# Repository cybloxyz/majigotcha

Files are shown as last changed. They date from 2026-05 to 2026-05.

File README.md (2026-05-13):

# MAJIGOTCHA!
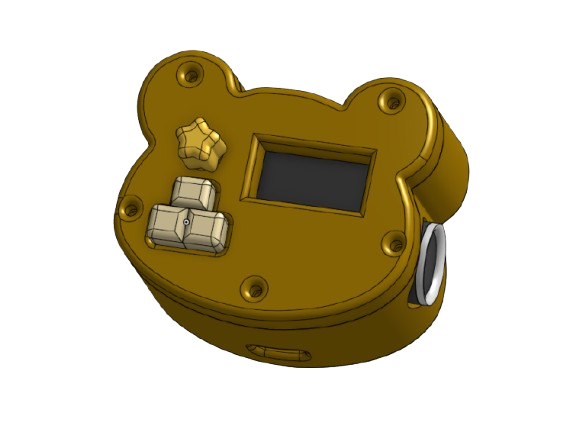
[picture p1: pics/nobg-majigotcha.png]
majigotcha

MAJIGOTCHA is a handheld digital pet in a small, bear head-shaped device. Users nurture a virtual creature from hatching through different life stages by feeding, cleaning, and playing with it using three buttons. Proper care determines its growth, while neglect can cause it to die.
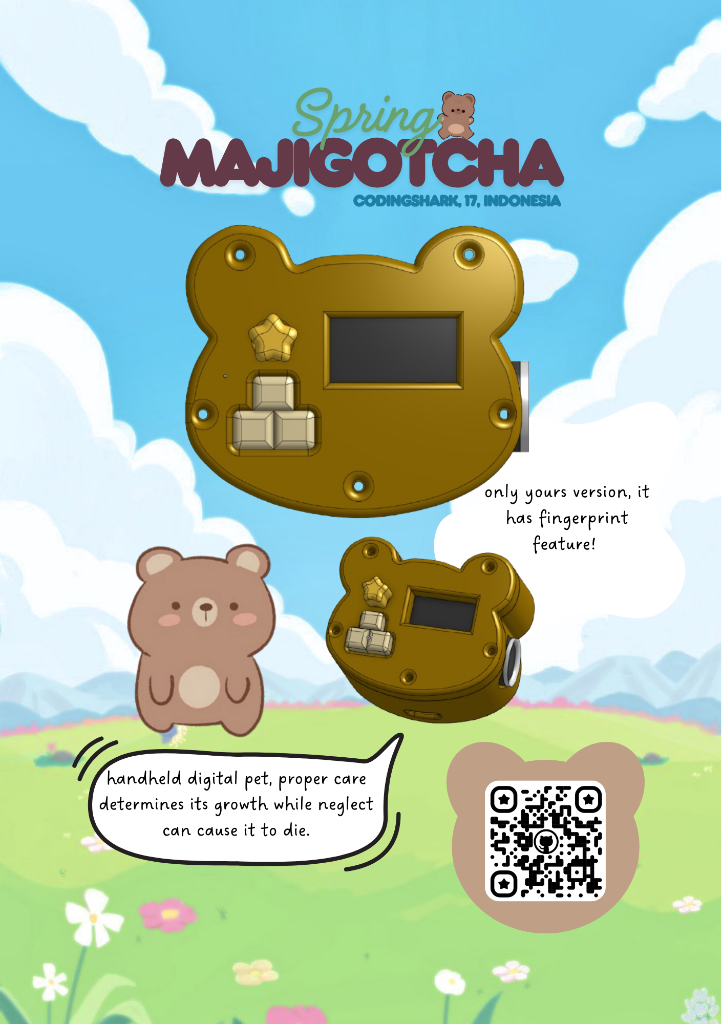
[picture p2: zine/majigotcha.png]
majigotcha zine


## why MAJIGOTCHA?
can't afford the real tamagotchi? yeah that is why i build my own, it is not tamagotchi it is MAJIGOTCHA, it has my dream features such fingerprint and touch sensor, i make this because my sister is really dream to have a tamagotchi but since it is too expensive to buy i prefer make this by my self, since i want something more than just a tamagotchi.

## features
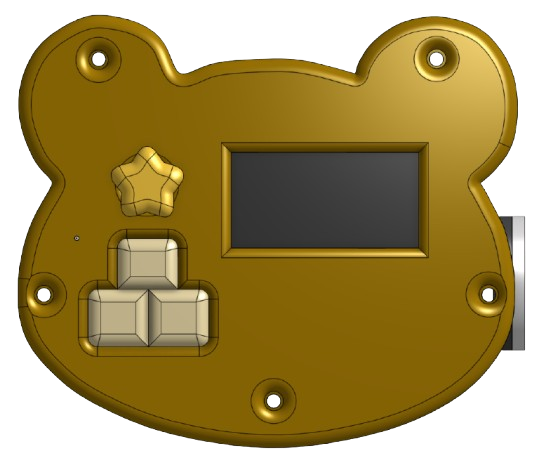
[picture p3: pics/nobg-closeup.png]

this is the first version of MAJIGOTCHA! it has really great features lemme break down:
> touch sensor, this mean you could pat your pet! tame it!

> fingerprint sensor, make it only yours..it will recognizes your fingerprint and can only be tamed with you.

> potentiometer scroll, since this MAJIGOTCHA has more complex features, the screen-menu could be navigate by potentiometer and button.

> in future i will upgrade this MAJIGOTCHA firmware to OTA and various casing.

## code example, pcb and schema
i made the case using [onshape](https://onshape.com) and here is the document link [MAJIGOTCHA-case](https://cad.onshape.com/documents/353c81332f9ae163598e6183/w/df33fd15e80ae307a4e30d2f/e/6c68072ba9f649a3b4a35ab0)
i am using RV09 vertical potentiometer so it will be solderen onPCB and for things such OLED, TTP223, HLK-ZW101 i use pinHeader 2.54 instead
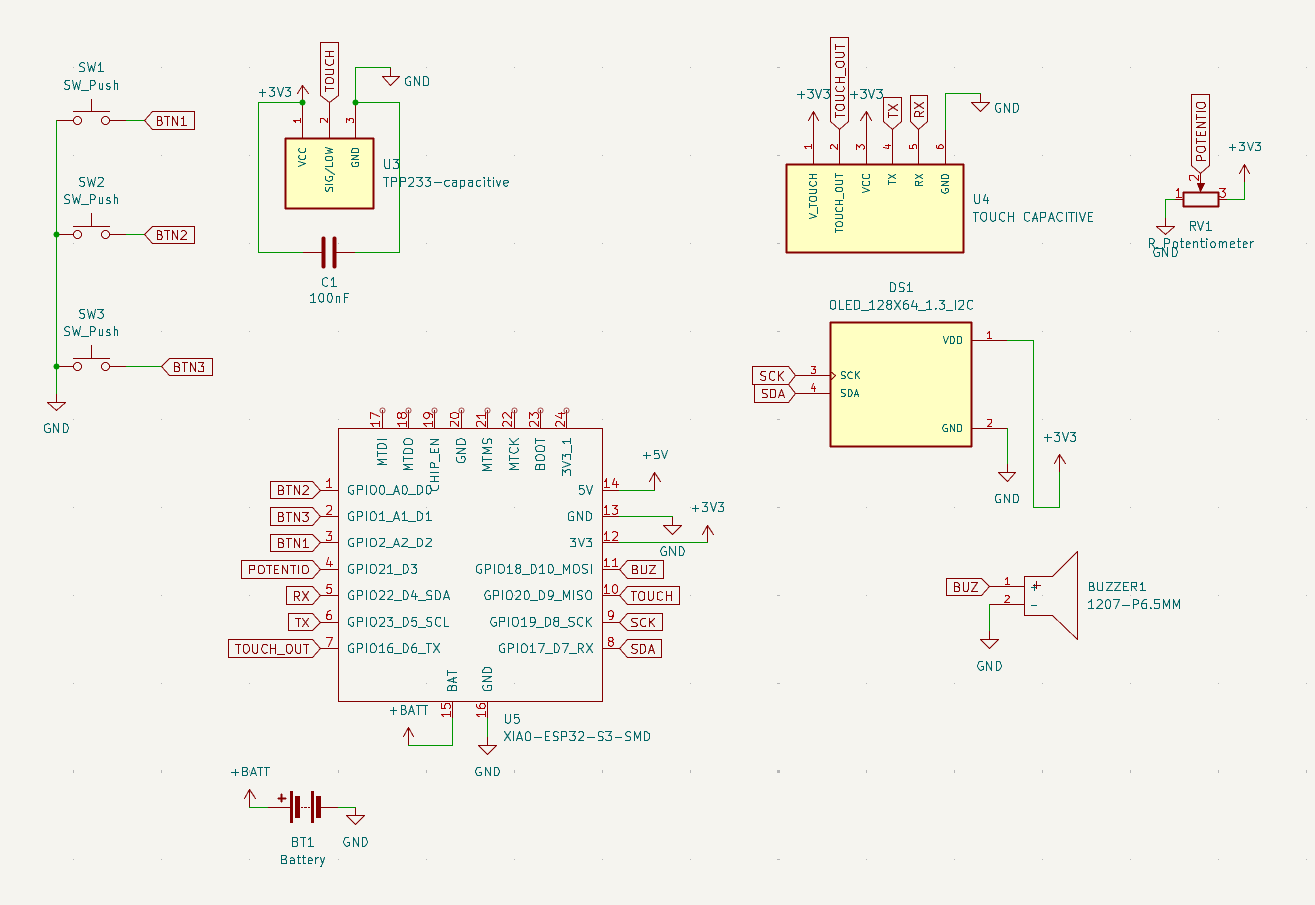
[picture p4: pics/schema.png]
schema

in this schema i'm using global labels since it is easier to understand and to read, for the PCB it is 2 layer, and contain vias, the pcb's size is not more than 50mmx50mm which it resulting in cheaper price.
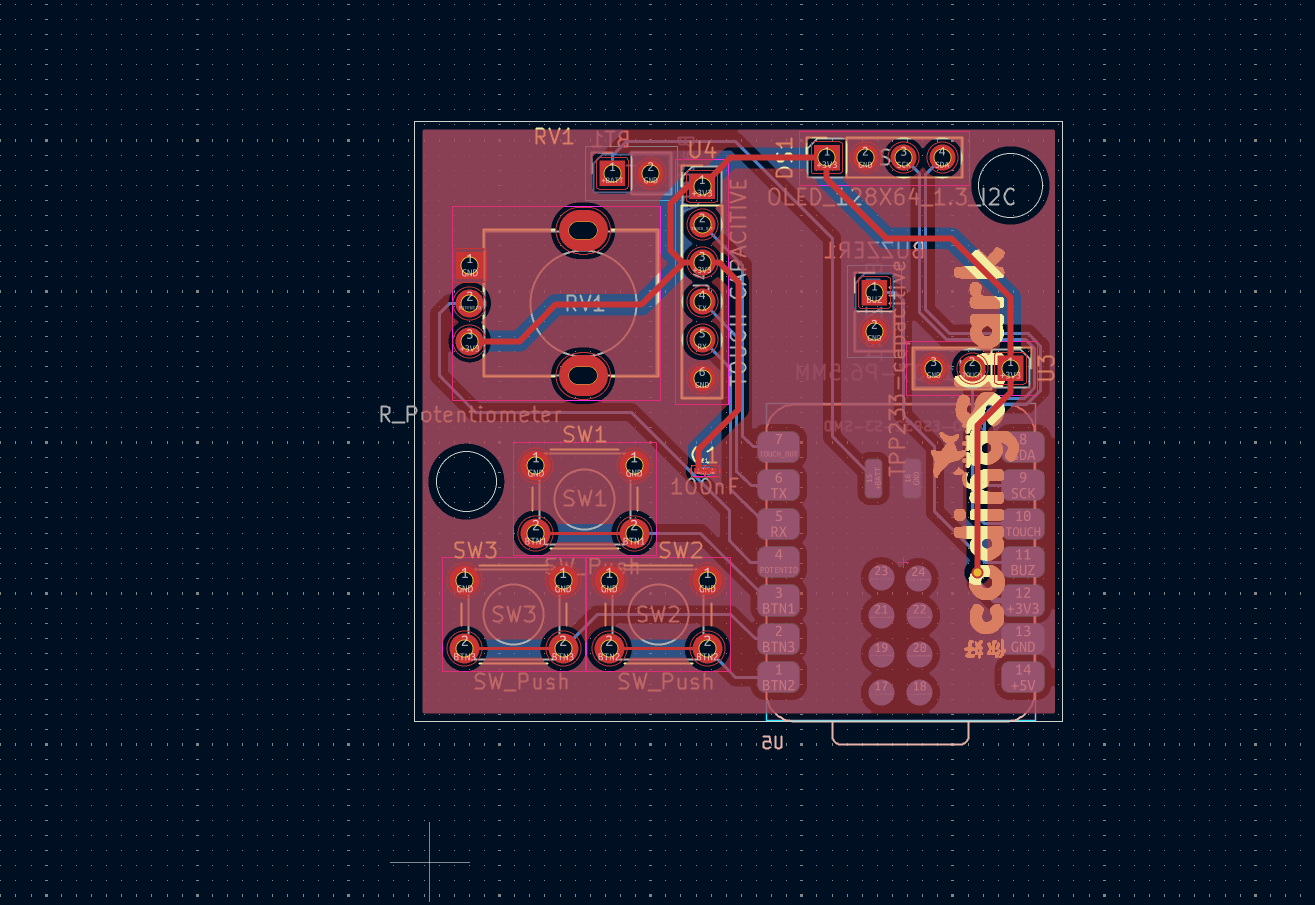
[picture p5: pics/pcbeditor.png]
pcb editor

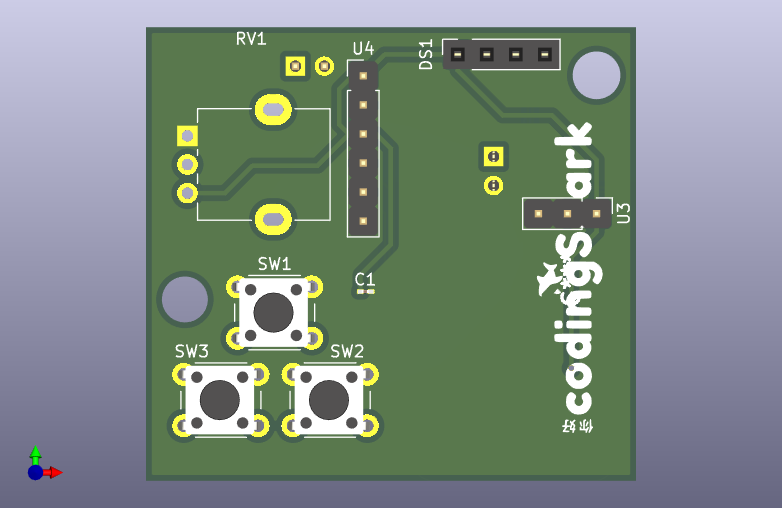
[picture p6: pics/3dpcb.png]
pcb


this MAJIGOTCHA is similar to tamagotchi BUT it is has more unique features, in here every stats even tame, inTamingProgress or notTame is has it own sprite, here is the bitmaps example:
```
const unsigned char PROGMEM notTame[] = {
  0b00000000, 0b00000000,
  0b00000000, 0b00000000,
  0b00001100, 0b01100000,
  0b00010011, 0b10010000,
  0b00010000, 0b00010000,
  0b00100100, 0b01001000,
  0b00010010, 0b10010000,
  0b00010000, 0b00010000,
  0b00001000, 0b00100000,
  0b00000111, 0b11000000,
  0b00001000, 0b00100000,
  0b00010100, 0b01010000,
  0b00010010, 0b10010000,
  0b00001100, 0b01100000,
  0b00010011, 0b10010000,
  0b00001100, 0b01100000
};
```
in notTame stat it means you rarely identify your fingerprint and interact with him, remember it is only you and some of your friends fingerprint! other than that he will very very badMood!
```
const unsigned char PROGMEM curious[] = {
  0b00000000, 0b00000000,
  0b00000000, 0b00000000,
  0b00001100, 0b01100000,
  0b00010011, 0b10010000,
  0b00010000, 0b00010000,
  0b00001010, 0b10100000,
  0b00010010, 0b10010000,
  0b00010000, 0b00010000,
  0b00001000, 0b00100000,
  0b00000111, 0b11000000,
  0b00001000, 0b00100000,
  0b00010100, 0b01010000,
  0b00010010, 0b10010000,
  0b00001100, 0b01100000,
  0b00010011, 0b10010000,
  0b00001100, 0b01100000
};
```
curious stat is when his tame progress is around 50 like more than 30 but less than 50, he starts curious with you! keep interact with him until he is happy!
```
const unsigned char PROGMEM happy[] = {
  0b00000000, 0b00000000,
  0b00000000, 0b00000000,
  0b00001100, 0b01100000,
  0b00010011, 0b10010000,
  0b00010000, 0b00010000,
  0b00001010, 0b10100000,
  0b00010001, 0b00010000,
  0b00010000, 0b00010000,
  0b00001000, 0b00100000,
  0b00000111, 0b11000000,
  0b00001000, 0b00100000,
  0b00010100, 0b01010000,
  0b00010010, 0b10010000,
  0b00001100, 0b01100000,
  0b00010011, 0b10010000,
  0b00001100, 0b01100000
};
```
if you reached happy! it means he likes you so much and he is happy to be with you! keep it like this and you both will be good friends!

## components
| no | name  | qty | price in idr |
|---|---|-----|---|
| 1 | [seeeduino xiao esp32-c6](https://shopee.co.id/Pre-Soldered-Seeeduino-Xiao-ESP32-C3-C6-S3-nRF52840-Mini-Development-Board-wifi-module-bluetooth5.0-i.1733652584.44605902551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) | 1 | 125000 |
| 2 | [OLED 1.3inch 4 pin](https://shopee.co.id/Oled-1.3-inch-White-128X64-LCD-LED-Display-I2C-SPI-i.29614947.15299206834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) | 1 | 60000 |
| 3 | [LiPo battery 1000mAh 3.7V](https://shopee.co.id/Baterai-lithium-polimer-1000mah-523450-1500mah-803450-i.6828741.7404713970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) | 1 | 70000 |
| 4 | [SW Push Tactile button](https://shopee.co.id/Tombol-Reset-saklar-Tactile-Push-Button-Micro-Switch-6x6-mm-4Pin-DIP-i.7849796.24862806415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) | 3 | 12000 |
| 5 | [RV09 20k Potentiometer](https://shopee.co.id/Potentiometer-Potensiometer-RV09-potensio-Mono-1-2-5-10-20-50-100-K-i.48406045.22301052102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) | 1 | 8000 |
| 6 | [TP223 capacitive touch sensor](https://shopee.co.id/MERAH-Saklar-Sentuh-Touch-Sensor-Capacitive-TTP223-Switch-Arduino-i.6406600.1153531563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) | 1 | 2000 |
| 7 | [HLK-ZW101 capacitive fingerprint](https://shopee.co.id/modul-fingerprint-capacitive-fingerprint-sensor-modul-kapasitas-50-profil-sidik-jari-support-arduino-esp32-i.108345327.28986833146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) | 1 | 120000 |
| 8 | [2.54 pin header](https://shopee.co.id/PIN-HEADER-MALE-STRIP-SINGLE-ROW-1X40-2.54MM-BLACK-HITAM-FOR-ARDUINO-MINI-NANO-i.62956347.5909650283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) | 40  | 10000 |
| 9 | [female to female cable](https://shopee.co.id/Kabel-Jumper-40PCS-20CM-Male-to-Female-Female-to-Female-Male-to-Male-Dupont-%E2%80%93-Kabel-Koneksi-untuk-Breadboard-i.62956347.1063975553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) | 40  | 10000 |
| 10 | [passive piezoelectric buzzer](https://shopee.co.id/Passive-Buzzer-3-12V-16-Ohm-BAGUS-12X8.5-mm-Pasive-Buzer-Pasif-Buser-i.193335132.52301383875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) | 1 | 2000 |
| 11 | [female pin header (pin socket)](https://shopee.co.id/1x40p-Female-Pin-Header-2.54mm-40-Pin-Single-Row-PCB-Connector-Betina-i.6406600.1153531501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) | 20  | 10000 |
| 12 | [connector XH2P housing](https://shopee.co.id/CONNECTOR-XH2.54-4P-PIN-FEMALE-20CM-CABLE-JST-2.54MM-SOCKET-CON-STOCKO-i.62956347.23700082559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) | 20  | 10000 |
| 13 | [jlcpcb](https://jlcpcb.com) | 5 | 65000 |
| 14 | [case](https://shopee.co.id/Jasa-Cetak-3D-Print-PLA-PLA-PETG-ABS-TPU-Nylon-Carbon-Fiber-Multicolor-Polycarbonate-Resin-i.81557195.43001716747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) | 1 | 40000 |
| total | Rp.544.000

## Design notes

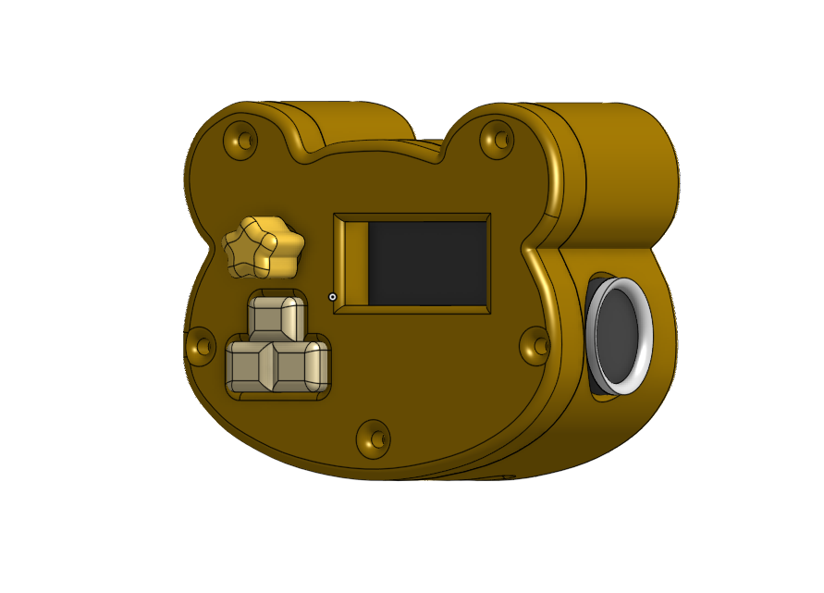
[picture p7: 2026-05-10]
pics/majigotcha2.png

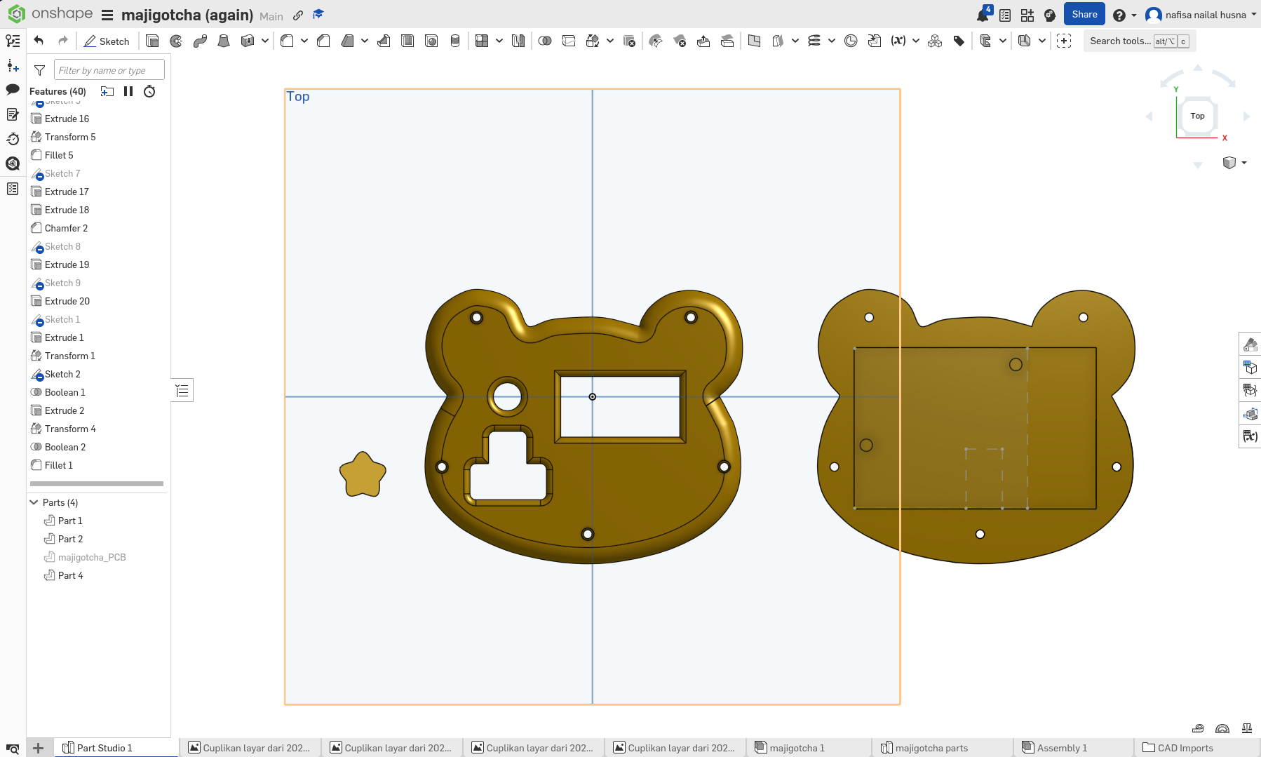
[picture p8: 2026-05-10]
pics/case.png

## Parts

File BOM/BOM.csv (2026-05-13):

no | name | url | qty | price_idr | subtotal_idr
1 | Seeed Studio XIAO ESP32-C6 | https://shopee.co.id/Pre-Soldered-Seeeduino-Xiao-ESP32-C3-C6-S3-nRF52840-Mini-Development-Board-wifi-module-bluetooth5.0-i.1733652584.44605902551 | 1 | 125000 | 125000
2 | OLED 1.3 inch 4-pin I2C | https://shopee.co.id/Oled-1.3-inch-White-128X64-LCD-LED-Display-I2C-SPI-i.29614947.15299206834 | 1 | 60000 | 60000
3 | LiPo Battery 1000mAh 3.7V | https://shopee.co.id/Baterai-lithium-polimer-1000mah-523450-1500mah-803450-i.6828741.7404713970 | 1 | 70000 | 70000
4 | Push Button Tactile Switch 6x6mm | https://shopee.co.id/Tombol-Reset-saklar-Tactile-Push-Button-Micro-Switch-6x6-mm-4Pin-DIP-i.7849796.24862806415 | 3 | 4000 | 12000
5 | Potentiometer RV09 20k Mono | https://shopee.co.id/Potentiometer-Potensiometer-RV09-potensio-Mono-1-2-5-10-20-50-100-K-i.48406045.22301052102 | 1 | 8000 | 8000
6 | TTP223 Capacitive Touch Sensor | https://shopee.co.id/MERAH-Saklar-Sentuh-Touch-Sensor-Capacitive-TTP223-Switch-Arduino-i.6406600.1153531563 | 1 | 2000 | 2000
7 | HLK-ZW101 Capacitive Fingerprint Sensor | https://shopee.co.id/modul-fingerprint-capacitive-fingerprint-sensor-modul-kapasitas-50-profil-sidik-jari-support-arduino-esp32-i.108345327.28986833146 | 1 | 120000 | 120000
8 | Male Pin Header 2.54mm (1x40) | https://shopee.co.id/PIN-HEADER-MALE-STRIP-SINGLE-ROW-1X40-2.54MM-BLACK-HITAM-FOR-ARDUINO-MINI-NANO-i.62956347.5909650283 | 1 | 10000 | 10000
9 | Jumper Cable Female to Female 20cm | https://shopee.co.id/Kabel-Jumper-40PCS-20CM-Male-to-Female-Female-to-Female-Male-to-Male-Dupont-%E2%80%93-Kabel-Koneksi-untuk-Breadboard-i.62956347.1063975553 | 1 | 10000 | 10000
10 | Passive Piezoelectric Buzzer | https://shopee.co.id/Passive-Buzzer-3-12V-16-Ohm-BAGUS-12X8.5-mm-Pasive-Buzer-Pasif-Buser-i.193335132.52301383875 | 1 | 2000 | 2000
11 | Female Pin Header 2.54mm (1x40) | https://shopee.co.id/1x40p-Female-Pin-Header-2.54mm-40-Pin-Single-Row-PCB-Connector-Betina-i.6406600.1153531501 | 1 | 10000 | 10000
12 | Connector JST-XH 2.54mm 2P Housing | https://shopee.co.id/CONNECTOR-XH2.54-4P-PIN-FEMALE-20CM-CABLE-JST-2.54MM-SOCKET-CON-STOCKO-i.62956347.23700082559 | 1 | 10000 | 10000
13 | JLCPCB Manufacturing Service | https://jlcpcb.com | 1 | 65000 | 65000
14 | 3D Printed Case (Custom) | https://shopee.co.id/Jasa-Cetak-3D-Print-PLA-PLA-PETG-ABS-TPU-Nylon-Carbon-Fiber-Multicolor-Polycarbonate-Resin-i.81557195.43001716747 | 1 | 40000 | 40000
 |  |  | Total |  | 544000

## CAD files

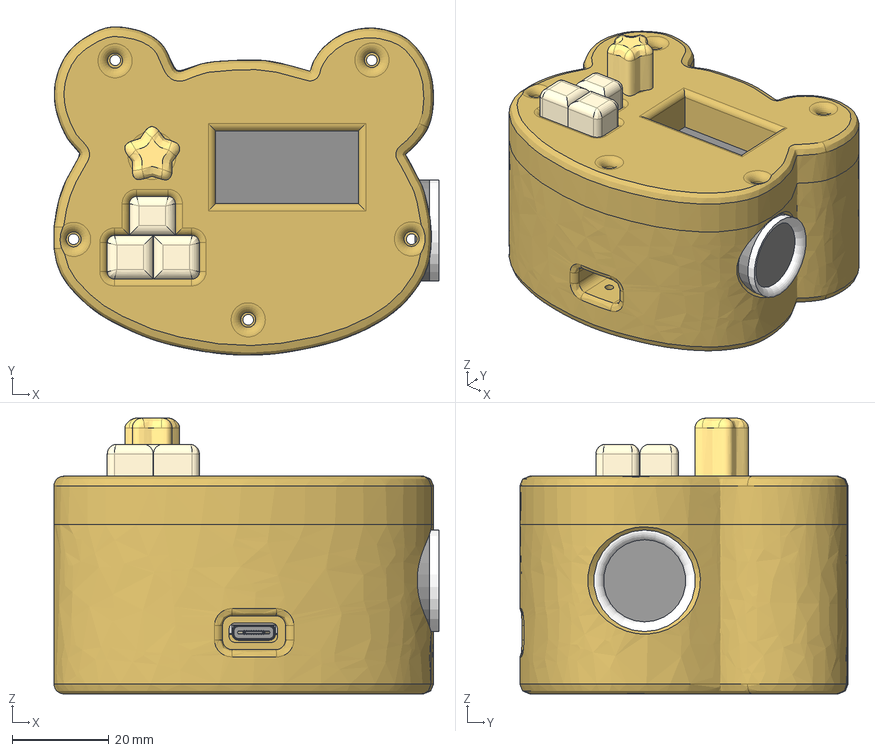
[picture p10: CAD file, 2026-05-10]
cad/STEPFILES/Assembled MAJIGOTCHA.step
79.6 x 67.9 x 57.0 mm
Display 1.3 OLED (Mauro) v5 x 4
majigotcha_PCB
Seeed Studio XIAO ESP32C6 v2 x 7
Shield
U.FL-R-SMT-1_10_ v1
Seeed Studio XIAO-ESP32-S3 (Sense)
Pins x 8
BOSS-EXTRUDE14_10_
MIRROR2
BOSS-EXTRUDE14_11_
BOSS-EXTRUDE14_12_
BOSS-EXTRUDE14_1_
BOSS-EXTRUDE7_5_
BOSS-EXTRUDE14_8_
BOSS-EXTRUDE7_6_
BOSS-EXTRUDE7_3_
BOSS-EXTRUDE7_4_
BOSS-EXTRUDE14_9_
BOSS-EXTRUDE7_8_
BOSS-EXTRUDE7_9_
BOSS-EXTRUDE7_2_
BOSS-EXTRUDE14_3_
BOSS-EXTRUDE7_7_
BOSS-EXTRUDE14_7_
BOSS-EXTRUDE14_5_
BOSS-EXTRUDE7_1_
BOSS-EXTRUDE14_6_
BOSS-EXTRUDE14_4_
BOSS-EXTRUDE14_2_
CUT-EXTRUDE5

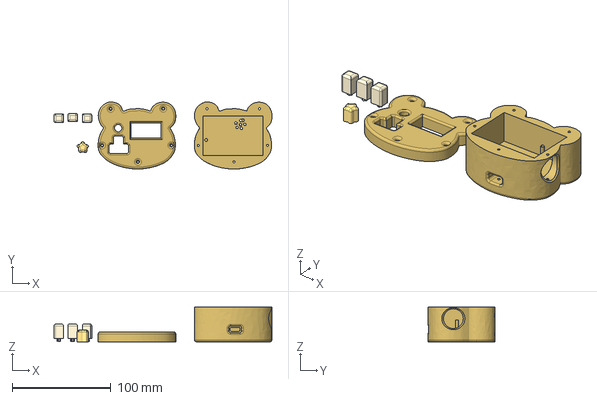
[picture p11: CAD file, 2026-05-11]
cad/STEPFILES/MAJIGOTCHA.step
220.3 x 67.9 x 35.0 mm

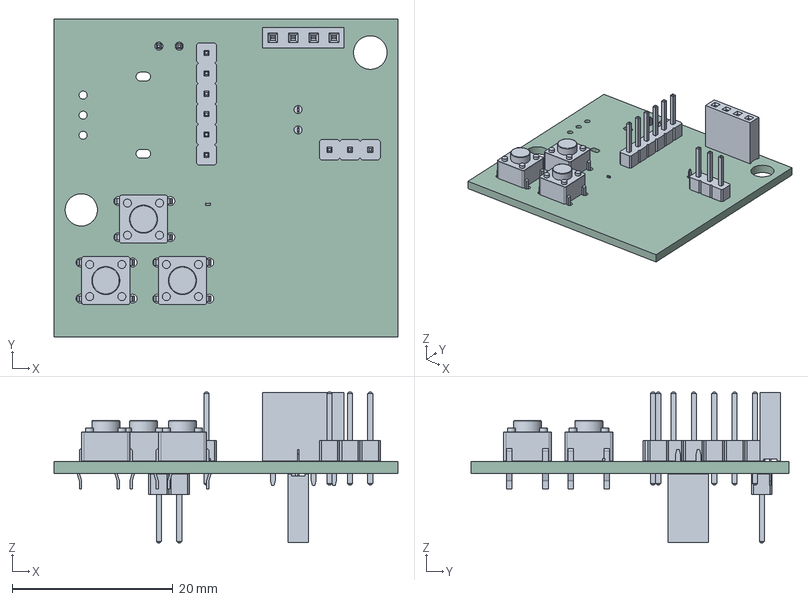
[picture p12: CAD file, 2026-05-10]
pcb/majigotcha.step
42.8 x 39.6 x 18.8 mm
SW_PUSH_6mm_H5mm x 3
PinHeader_1x06_P2.54mm_Vertical
PinHeader_1x03_P2.54mm_Vertical
PinSocket_1x04_P2.54mm_Vertical
C_0201_0603Metric
PinSocket_1x02_P2.54mm_Vertical
PinHeader_1x02_P2.54mm_Vertical
majigotcha_PCB

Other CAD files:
cad/MAJIGOTCHA.stl

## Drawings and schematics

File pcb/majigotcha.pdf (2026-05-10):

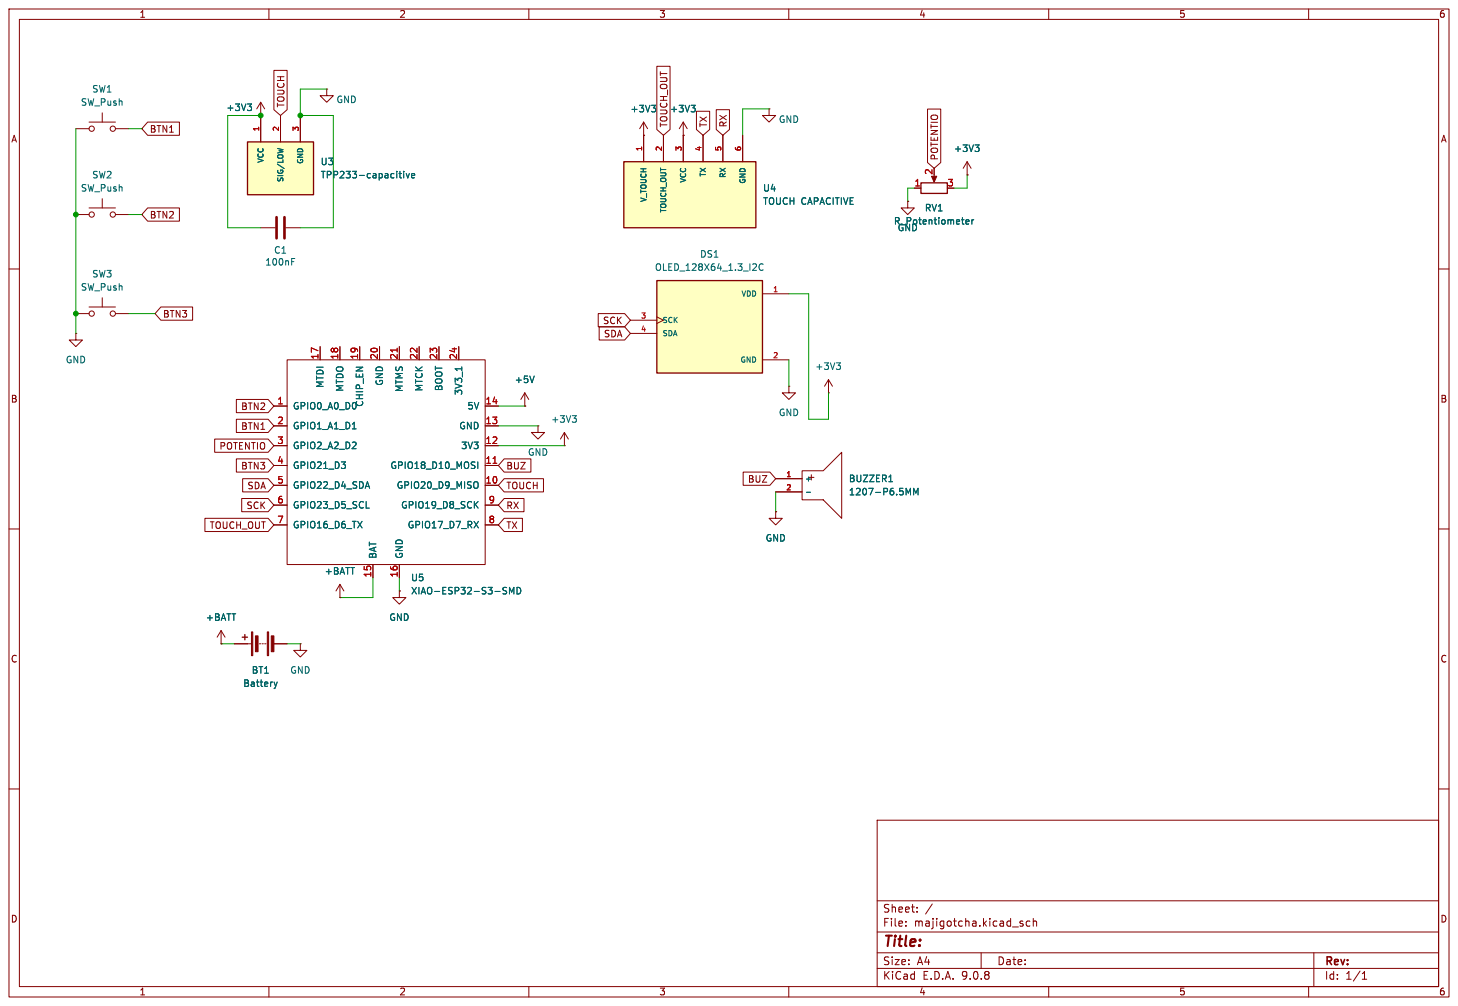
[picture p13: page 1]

6 U4 TOUCH CAPACITIVE GND GND

Id: 1/1 Title: File: majigotcha.kicad_sch Sheet: /

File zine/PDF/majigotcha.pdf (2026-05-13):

# MAJIGOTCHA

# Spring

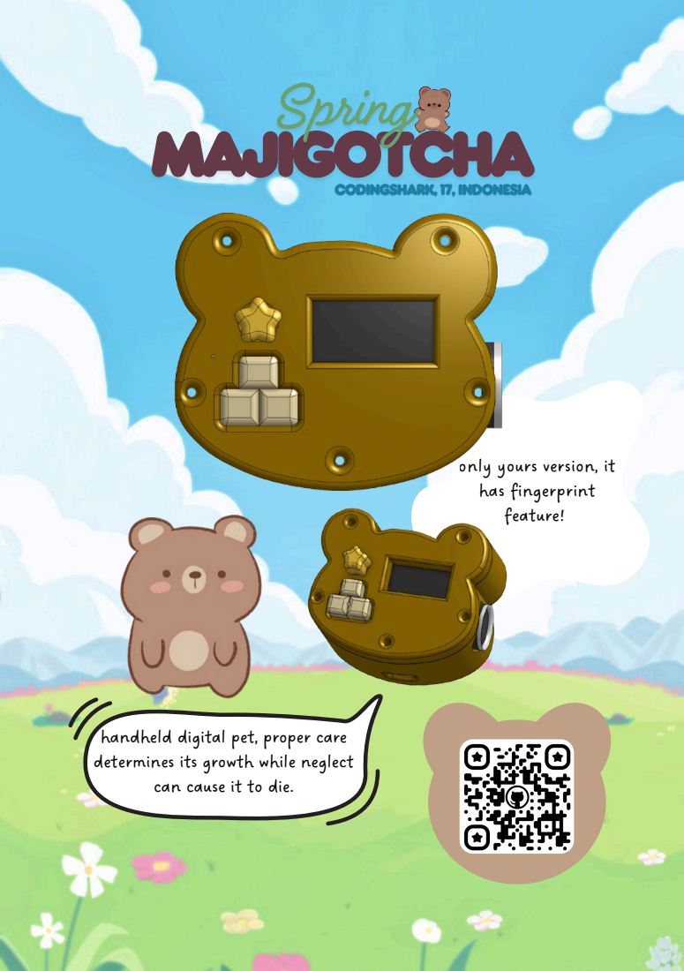
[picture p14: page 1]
codingshark,17,indonesia

only yours version, it
has fingerprint
feature!

handheld digital pet, proper care
determines its growth while neglect
can cause it to die.

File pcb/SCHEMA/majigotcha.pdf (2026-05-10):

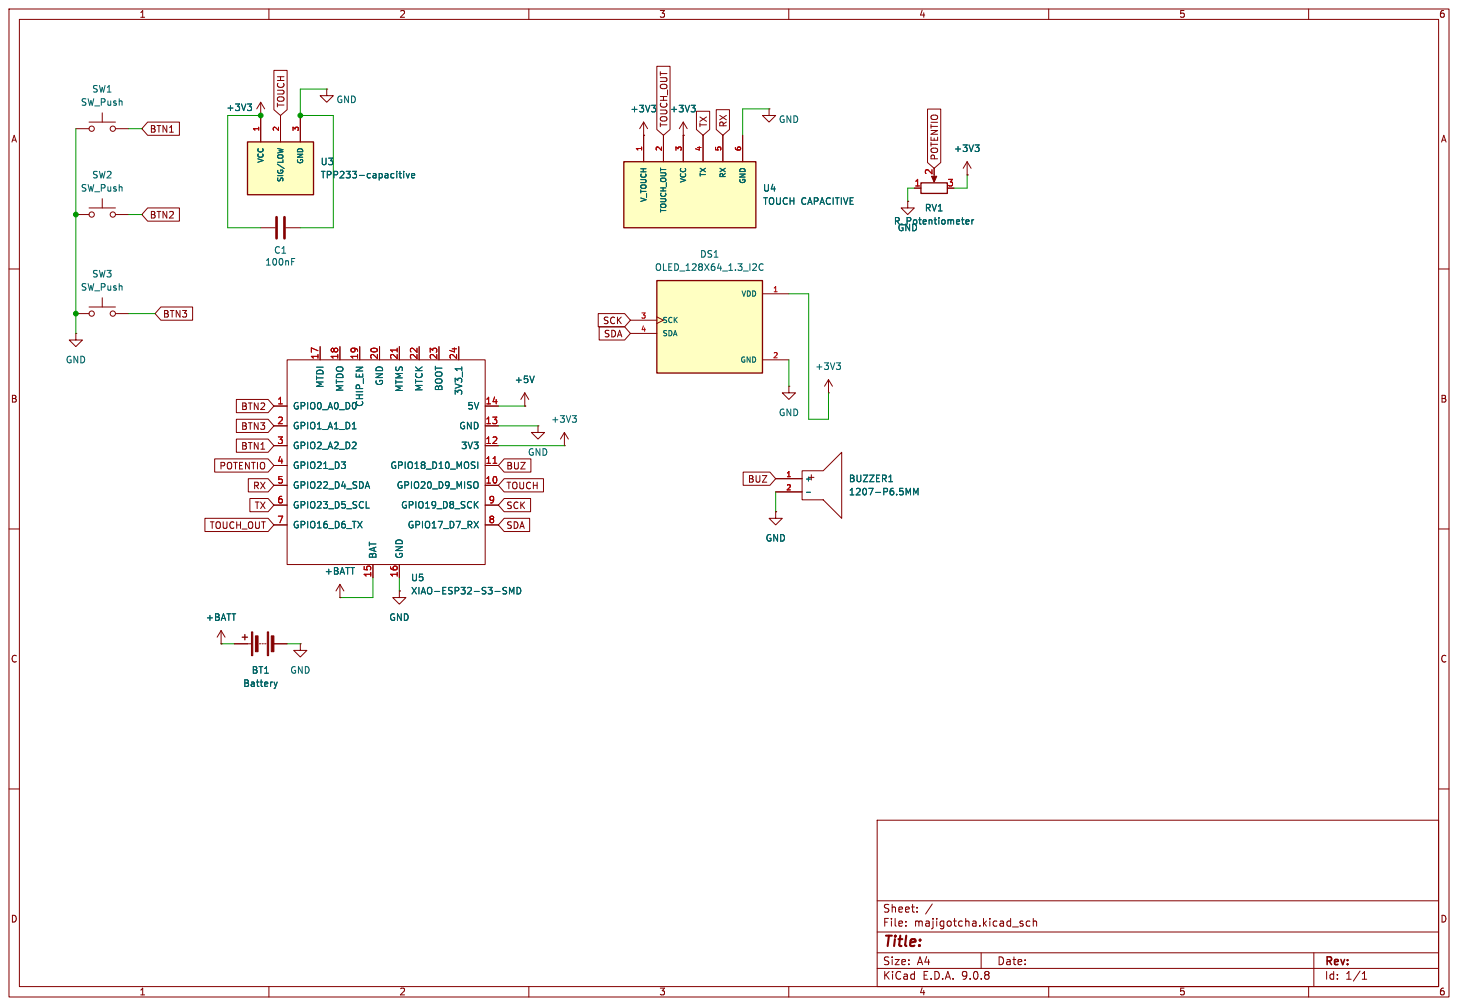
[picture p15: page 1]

Id: 1/1 Title: File: majigotcha.kicad_sch Sheet: / +BATT

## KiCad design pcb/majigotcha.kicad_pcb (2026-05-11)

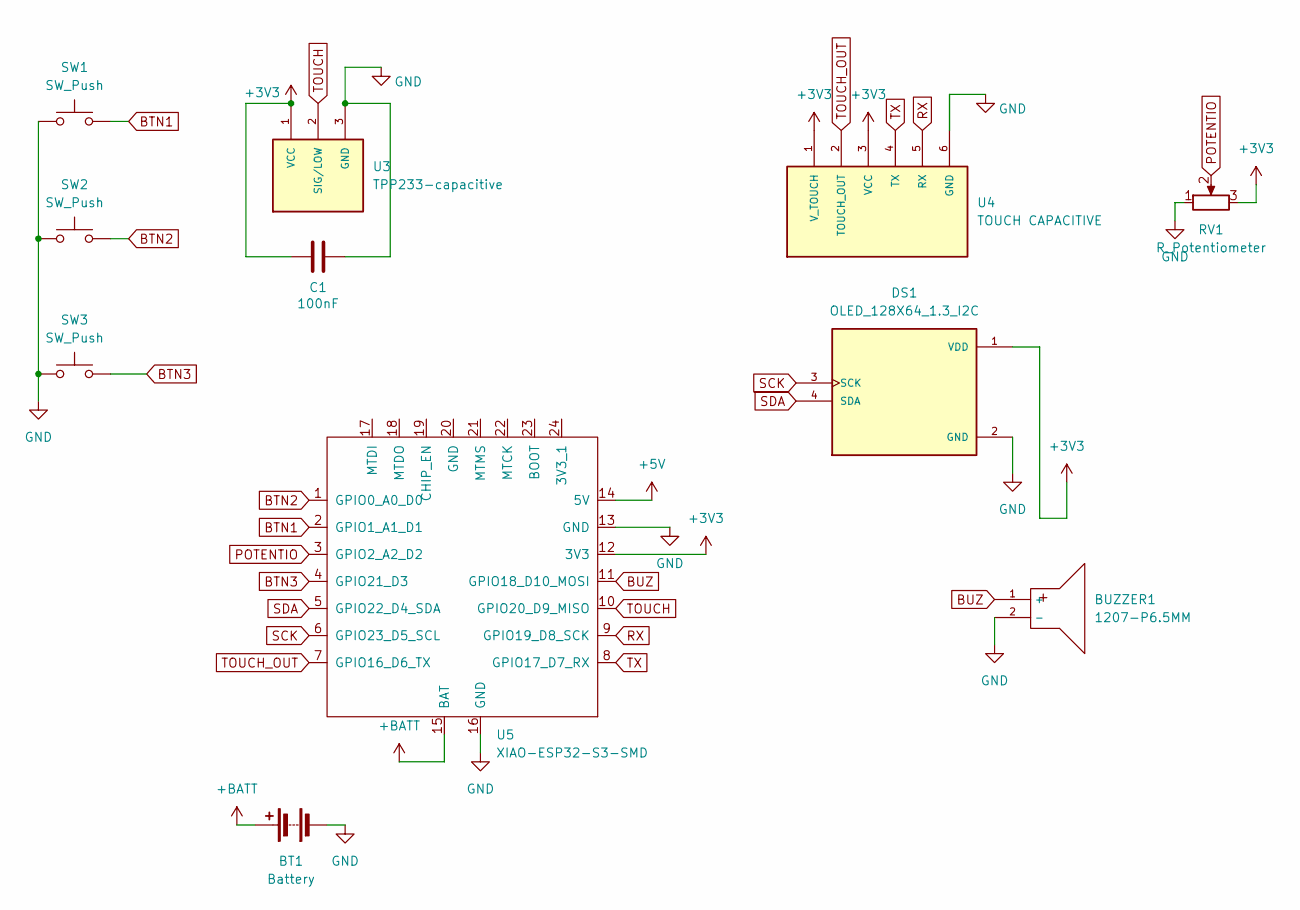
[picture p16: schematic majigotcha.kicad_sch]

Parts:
BT1: Battery; PinHeader_1x02_P2.54mm_Vertical
BUZZER1: 1207-P6.5MM; PinSocket_1x02_P2.54mm_Vertical; LCSC C49246964
C1: 100nF; C_0201_0603Metric_Pad0.64x0.40mm_HandSolder
DS1: OLED_128X64_1.3_I2C; PinSocket_1x04_P2.54mm_Vertical; PARTREV NA
RV1: R_Potentiometer; Potentiometer_Alpha_RD901F-40-00D_Single_Vertical
SW1, SW2, SW3: SW_Push; SW_PUSH_6mm_H5mm
U3: TPP233-capacitive; PinHeader_1x03_P2.54mm_Vertical; DigiKey_Part_Number 1738-1041-ND
U4: TOUCH CAPACITIVE; PinHeader_1x06_P2.54mm_Vertical; DigiKey_Part_Number 1738-1041-ND
U5: XIAO-ESP32-S3-SMD; XIAO-ESP32C6-SMD

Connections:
+3V3: C1.1, DS1.1 (VDD), RV1.3, U3.1 (VCC), U4.1 (V_TOUCH), U4.3 (VCC), U5.12 (3V3)
+5V: U5.14 (5V)
+BATT: BT1.1 (+), U5.15 (BAT)
BTN1: SW1.2, U5.2 (GPIO1_A1_D1)
BTN2: SW2.2, U5.1 (GPIO0_A0_D0)
BTN3: SW3.2, U5.4 (GPIO21_D3)
BUZ: BUZZER1.1 (+), U5.11 (GPIO18_D10_MOSI)
GND: BT1.2 (-), BUZZER1.2 (-), C1.2, DS1.2 (GND), RV1.1, SW1.1, SW2.1, SW3.1, U3.3 (GND), U4.6 (GND), U5.13 (GND), U5.16 (GND)
POTENTIO: RV1.2, U5.3 (GPIO2_A2_D2)
RX: U4.5 (RX), U5.9 (GPIO19_D8_SCK)
SCK: DS1.3 (SCK), U5.6 (GPIO23_D5_SCL)
SDA: DS1.4 (SDA), U5.5 (GPIO22_D4_SDA)
TOUCH: U3.2 (SIG/LOW), U5.10 (GPIO20_D9_MISO)
TOUCH_OUT: U4.2 (TOUCH_OUT), U5.7 (GPIO16_D6_TX)
TX: U4.4 (TX), U5.8 (GPIO17_D7_RX)

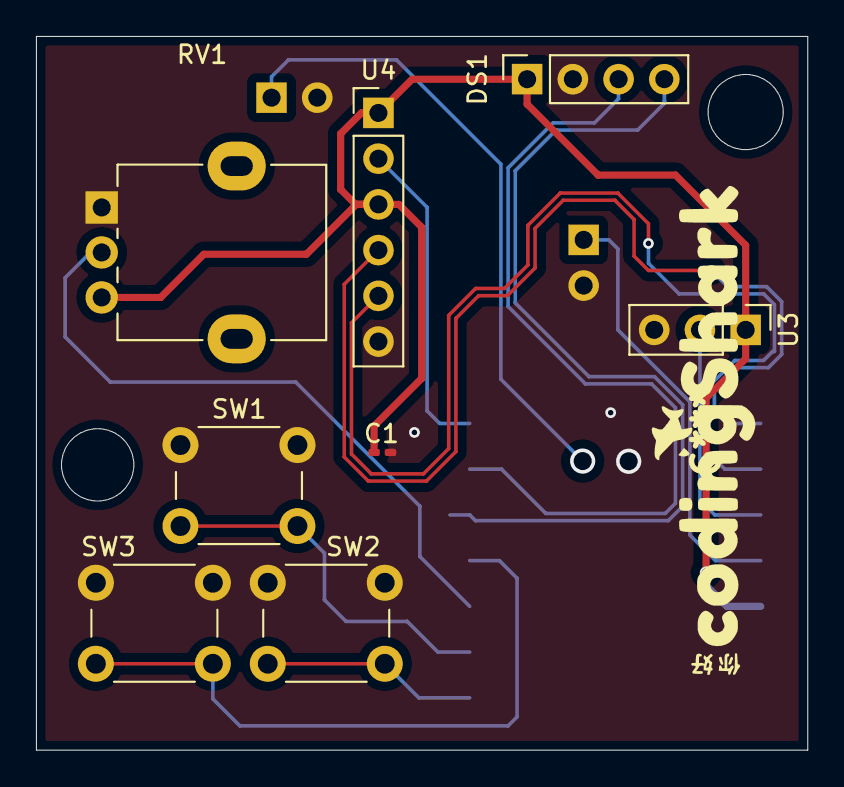
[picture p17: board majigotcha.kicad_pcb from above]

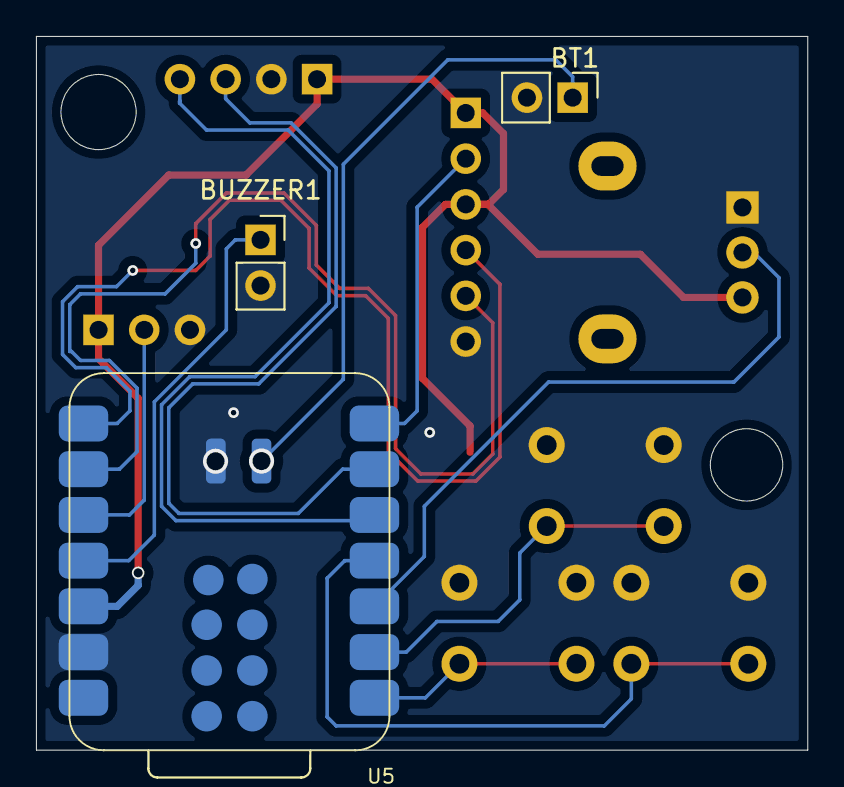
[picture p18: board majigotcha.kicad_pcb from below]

Board: 2 copper layers, 42.8 x 39.6 mm, 11 parts (3 on the bottom side), 14 nets.

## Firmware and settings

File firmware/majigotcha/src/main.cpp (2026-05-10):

#include <Wire.h>
#include <Adafruit_GFX.h>
#include <Adafruit_SH110X.h>
#include <SPI.h>

#define SCREEN_WIDTH 128
#define SCREEN_HEIGHT 64
#define OLED_RESET -1

Adafruit_SH1106G display(SCREEN_HEIGHT, SCREEN_WIDTH, OLED_RESET, &Wire);

#define BTN_SW1 D1
#define BTN_SW2 D0
#define BTN_SW3 D3

#define POTENTIO A2
#define BUZZ D10

#define TOUCHOUT_FINGERPRINT D6
#define RX_FINGERPRINT D4
#define TX_FINGERPRINT D5
#define TOUCH D9

#define SDA_OLED D7
#define SCK_OLED D8

struct Pet
{
    int hunger;
    int happiness;
    int energy;
    int health;
    int skill;
    int tame;
    unsigned long age;
};

Pet pet;

enum Screen 
{
    SCREEN_MAIN,
    SCREEN_FEED,
    SCREEN_PLAY,
    SCREEN_HOSPITAL,
    SCREEN_PRIVATE,
    SCREEN_SLEEP
};

Screen currentScreen = SCREEN_MAIN;

void setup() {
    pinMode(BTN_SW1, INPUT_PULLUP);
    pinMode(BTN_SW2, INPUT_PULLUP);
    pinMode(BTN_SW3, INPUT_PULLUP);
    pinMode(BUZZ, OUTPUT);
    pinMode(POTENTIO, INPUT);
    pinMode(TOUCH, INPUT);
    pinMode(TOUCHOUT_FINGERPRINT, INPUT);
    mySerial.begin(57600);
    Serial.begin(9600);

    display.begin(0x3c, true);
    display.clearDisplay();
    display.setTextSize(1);
    display.setTextColor(SSH110X_WHITE);
    display.setCursor(0, 0);
    display.println('Majigotcha init...');
    display.display();
    delay(1000);

    pet.hunger = 80;
    pet.energy = 80;
    pet.health = 80;
    pet.happiness = 80;
    pet.skill = 0;
    pet.tame = 0;
    pet.age = 0;
}

unsigned long lastUpdateStat = 0;
unsigned long lastUpdateTame = 0;
unsigned long lastUpdateHealth = 0;

void updatePet() {
    if (millis() - lastUpdateStat > 10000) {
        pet.energy--;
        pet.hunger--;
        pet.happiness--;

        if (pet.hunger < 0) pet.hunger = 0;
        if (pet.energy < 0) pet.hunger = 0;
        if (pet.happiness < 0) pet.happiness = 0;

        pet.age += 5;
        lastUpdateStat = millis();
    }
    if (millis() - lastUpdateTame > 300000) {
        pet.tame--;

        if (pet.tame < 0) pet.tame = 0;
        lastUpdateTame = millis();
    }
    if (millis() - lastUpdateHealth > 720000) {
        pet.health--;

        if (pet.health < 0) pet.health = 0;
        lastUpdateHealth = millis();
    }
}

unsigned long lastButtonPress = 0;

void checkButtons() {
    if (millis() - lastButtonPress < 200) return;

    if (digitalRead(BTN_SW2) == LOW) {
        currentScreen = SCREEN_FEED;
        tone(BUZZ, 1000, 50);
        lastButtonPress = millis();
    }
    else if (digitalRead(BTN_SW3) == LOW) {
        currentScreen = SCREEN_PRIVATE;
        tone(BUZZ, 1200, 50);
        lastButtonPress = millis();
    }
}

bool menuOpen = false;
int menuSelection = 0;
const int NUM_MENU = 4; 

void checkMenu() {
    if (digitalRead(BTN_SW1) == LOW && (millis() - lastButtonPress > 300)) {
        if (!menuOpen) {
            menuOpen = true; 
            tone(BUZZ, 1500, 50);
        } else {
       
            if (menuSelection == 0) currentScreen = SCREEN_MAIN;
            else if (menuSelection == 1) currentScreen = SCREEN_PLAY;
            else if (menuSelection == 2) currentScreen = SCREEN_SLEEP;
            else if (menuSelection == 3) currentScreen = SCREEN_HOSPITAL;
            
            menuOpen = false; 
            tone(BUZZ, 2000, 100);
        }
        lastButtonPress = millis();
    }

    
    if (menuOpen) {
        int potValue = analogRead(POTENTIO); 
   
        menuSelection = map(potValue, 0, 4095, 0, NUM_MENU - 1);
    }
}

void handleScreenLogic() {
  switch(currentScreen) {

    case SCREEN_FEED:
      pet.hunger += 10;
      if (pet.hunger > 100) pet.hunger = 100;
      currentScreen = SCREEN_MAIN;
      break;

    case SCREEN_PLAY:
      pet.happiness += 10;
      pet.energy -= 5;
      if (pet.happiness > 100) pet.happiness = 100;
      if (pet.energy < 0) pet.energy = 0;
      currentScreen = SCREEN_MAIN;
      break;

    case SCREEN_SLEEP:
      pet.energy += 15;
      if (pet.energy > 100) pet.energy = 100;
      currentScreen = SCREEN_MAIN;
      break;

    case SCREEN_HOSPITAL:
      pet.health += 5;
      if (pet.health > 100) pet.health = 100;
      currentScreen = SCREEN_MAIN;
      break;

    case SCREEN_PRIVATE:
      pet.tame += 2;
      if (pet.tame > 100) pet.tame = 100;
      currentScreen = SCREEN_MAIN;
      break;

    case SCREEN_MAIN:
      break; 
  }
}

//stats
const unsigned char PROGMEM happy[] = {
  0b00000000, 0b00000000,
  0b00000000, 0b00000000,
  0b00001100, 0b01100000,
  0b00010011, 0b10010000,
  0b00010000, 0b00010000,
  0b00001010, 0b10100000,
  0b00010001, 0b00010000,
  0b00010000, 0b00010000,
  0b00001000, 0b00100000,
  0b00000111, 0b11000000,
  0b00001000, 0b00100000,
  0b00010100, 0b01010000,
  0b00010010, 0b10010000,
  0b00001100, 0b01100000,
  0b00010011, 0b10010000,
  0b00001100, 0b01100000
};

const unsigned char PROGMEM sleep[] = {
  0b00000000, 0b00000000,
  0b00000000, 0b00000000,
  0b00001100, 0b01100000,
  0b00010011, 0b10010000,
  0b00010000, 0b00010000,
  0b00001110, 0b11100000,
  0b00010001, 0b00010000,
  0b00010000, 0b00010000,
  0b00001000, 0b00100000,
  0b00000111, 0b11000000,
  0b00001000, 0b00100000,
  0b00010100, 0b01010000,
  0b00010010, 0b10010000,
  0b00001100, 0b01100000,
  0b00010011, 0b10010000,
  0b00001100, 0b01100000
};

const unsigned char PROGMEM hungry[] = {
  0b00000000, 0b00000000,
  0b00000000, 0b00000000,
  0b00001100, 0b01100000,
  0b00010011, 0b10010000,
  0b00010000, 0b00010000,
  0b00001010, 0b10100000,
  0b00010000, 0b00010000,
  0b00010011, 0b10010000,
  0b00001011, 0b10100000,
  0b00000111, 0b11000000,
  0b00001000, 0b00100000,
  0b00010100, 0b01010000,
  0b00010010, 0b10010000,
  0b00001100, 0b01100000,
  0b00010011, 0b10010000,
  0b00001100, 0b01100000
};

const unsigned char PROGMEM badMood[] = {
  0b00000000, 0b00000000,
  0b00000000, 0b00000000,
  0b00001100, 0b01100000,
  0b00010011, 0b10010000,
  0b00010000, 0b00010000,
  0b00001010, 0b10100000,
  0b00010000, 0b00010000,
  0b00010011, 0b10010000,
  0b00001000, 0b00100000,
  0b00000111, 0b11000000,
  0b00001000, 0b00100000,
  0b00010100, 0b01010000,
  0b00010010, 0b10010000,
  0b00001100, 0b01100000,
  0b00010011, 0b10010000,
  0b00001100, 0b01100000
};

const unsigned char PROGMEM sick[] = {
  0b00000000, 0b00000000,
  0b00000000, 0b00000000,
  0b00001100, 0b01100000,
  0b00010011, 0b10010000,
  0b00010000, 0b00010000,
  0b00001010, 0b10100000,
  0b00010100, 0b00010000,
  0b00010011, 0b10010000,
  0b00001000, 0b00100000,
  0b00000111, 0b11000000,
  0b00001000, 0b00100000,
  0b00010100, 0b01010000,
  0b00010010, 0b10010000,
  0b00001100, 0b01100000,
  0b00010011, 0b10010000,
  0b00001100, 0b01100000
};

const unsigned char PROGMEM sad[] = {
  0b00000000, 0b00000000,
  0b00000000, 0b00000000,
  0b00001100, 0b01100000,
  0b00010011, 0b10010000,
  0b00010000, 0b00010000,
  0b00001110, 0b11100000,
  0b00010100, 0b01010000,
  0b00010011, 0b10010000,
  0b00001000, 0b00100000,
  0b00000111, 0b11000000,
  0b00001000, 0b00100000,
  0b00010100, 0b01010000,
  0b00010010, 0b10010000,
  0b00001100, 0b01100000,
  0b00010011, 0b10010000,
  0b00001100, 0b01100000
};

const unsigned char PROGMEM curious[] = {
  0b00000000, 0b00000000,
  0b00000000, 0b00000000,
  0b00001100, 0b01100000,
  0b00010011, 0b10010000,
  0b00010000, 0b00010000,
  0b00001010, 0b10100000,
  0b00010010, 0b10010000,
  0b00010000, 0b00010000,
  0b00001000, 0b00100000,
  0b00000111, 0b11000000,
  0b00001000, 0b00100000,
  0b00010100, 0b01010000,
  0b00010010, 0b10010000,
  0b00001100, 0b01100000,
  0b00010011, 0b10010000,
  0b00001100, 0b01100000
};

const unsigned char PROGMEM aBitHappy[] = {
  0b00000000, 0b00000000,
  0b00000000, 0b00000000,
  0b00001100, 0b01100000,
  0b00010011, 0b10010000,
  0b00010000, 0b00010000,
  0b00001000, 0b00100000,
  0b00010010, 0b10010000,
  0b00010001, 0b00010000,
  0b00001000, 0b00100000,
  0b00000111, 0b11000000,
  0b00001000, 0b00100000,
  0b00010100, 0b01010000,
  0b00010010, 0b10010000,
  0b00001100, 0b01100000,
  0b00010011, 0b10010000,
  0b00001100, 0b01100000
};

const unsigned char PROGMEM notTame[] = {
  0b00000000, 0b00000000,
  0b00000000, 0b00000000,
  0b00001100, 0b01100000,
  0b00010011, 0b10010000,
  0b00010000, 0b00010000,
  0b00100100, 0b01001000,
  0b00010010, 0b10010000,
  0b00010000, 0b00010000,
  0b00001000, 0b00100000,
  0b00000111, 0b11000000,
  0b00001000, 0b00100000,
  0b00010100, 0b01010000,
  0b00010010, 0b10010000,
  0b00001100, 0b01100000,
  0b00010011, 0b10010000,
  0b00001100, 0b01100000
};

void render() {
  display.clearDisplay();

  // Choose the right sprite based on pet stats
  const unsigned char* sprite;
  if (currentScreen = SCREEN_SLEEP) {
    sprite = sleep;
  }
  else if (pet.health < 70) {
    sprite = sick;
  } 
  else if (pet.hunger < 30 || pet.happiness < 30 || pet.energy < 30) {
    sprite = sad;
  }  
  else if (pet.hunger < 40 || pet.happiness < 20 || pet.energy < 30) {
    sprite = badMood;
  }  
  else if (currentScreen = SCREEN_PRIVATE || pet.tame < 30) {
    sprite = notTame;
    if (pet.tame > 30) sprite = curious;
    if (pet.tame > 80) sprite = happy;
  }  
  else if (pet.hunger > 50 && pet.happiness > 50 && pet.energy > 50) {
    sprite = happy;
  } else {
    sprite = aBitHappy;
  }

  // Draw the pet sprite (centered horizontally, near the top)
  display.drawBitmap(56, 2, sprite, 16, 16, SSH1106_WHITE);

  // Draw stat bars below the pet
  display.setTextSize(1);

  display.setCursor(0, 24);
  display.print("HUN ");
  drawBar(24, 24, pet.hunger);

  display.setCursor(0, 34);
  display.print("HAP ");
  drawBar(24, 34, pet.happiness);

  display.setCursor(0, 44);
  display.print("ENG ");
  drawBar(24, 44, pet.energy);

  // Button labels at the bottom
  display.setCursor(0, 56);
  display.println("[Feed] [Play] [Sleep] [Health] [Tame]");

  display.display();
}

// Draws a stat bar: empty rectangle with a filled portion based on value (0 to 100)
void drawBar(int x, int y, int value) {
  int barWidth = 100;
  int barHeight = 6;
  int fillWidth = map(value, 0, 100, 0, barWidth);

  display.drawRect(x, y, barWidth, barHeight, SSH1106_WHITE);       // outline
  display.fillRect(x, y, fillWidth, barHeight, SSH1106_WHITE);      // filled portion
}

void loop() {
    checkButtons();
    checkMenu();
    updatePet();
    handleScreenLogic();
    render();
    delay(1000);
}

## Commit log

2026-05-01 finish the pcb
    [majigotcha-B_Cu.gbr, majigotcha-B_Mask.gbr, majigotcha-B_Paste.gbr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]
2026-05-10 add firmware! oh and change of pcb wiring
    [BOM.csv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]
2026-05-10 add README.md
    [Assembled MAJIGOTCHA.step, majigotcha.step]
2026-05-10 add stl file
    [MAJIGOTCHA.stl]
2026-05-10 update gerbers
    [majigotcha-B_Cu.gbr, majigotcha-B_Mask.gbr, majigotcha-B_Paste.gbr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]
2026-05-11 add 0.3mm tolerance
    [MAJIGOTCHA.step, majigotcha.step]
2026-05-11 add via in pad
    [majigotcha-B_Cu.gbr, majigotcha-B_Mask.gbr, majigotcha-B_Paste.gbr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]
2026-05-13 fix the links
    [BOM.csv]
2026-05-13 still fix links
    [BOM.csv]
